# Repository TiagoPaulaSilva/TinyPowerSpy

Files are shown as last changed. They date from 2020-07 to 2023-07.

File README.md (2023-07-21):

# Tiny PowerSpy

 

Tiny PowerSpy is an IoT device, a smart plug for energy monitoring in wall outlets.

#### Compatible with: 
* [BitsTunnel](https://github.com/import-tiago/BitsTunnel)

## PCB Preview
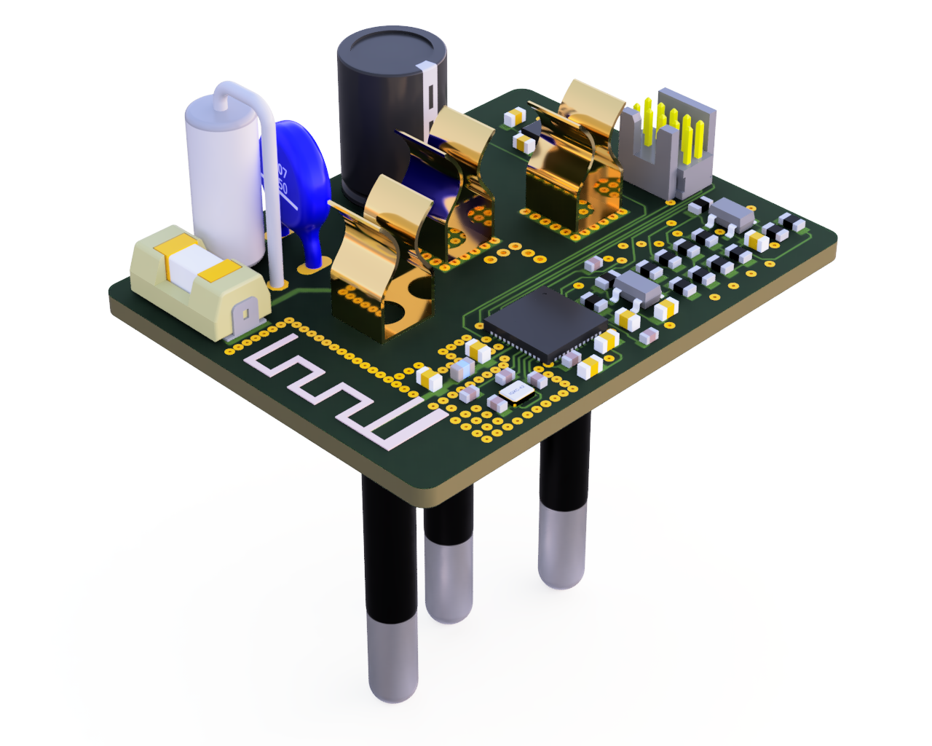
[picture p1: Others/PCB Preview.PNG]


## Enclosure Preview
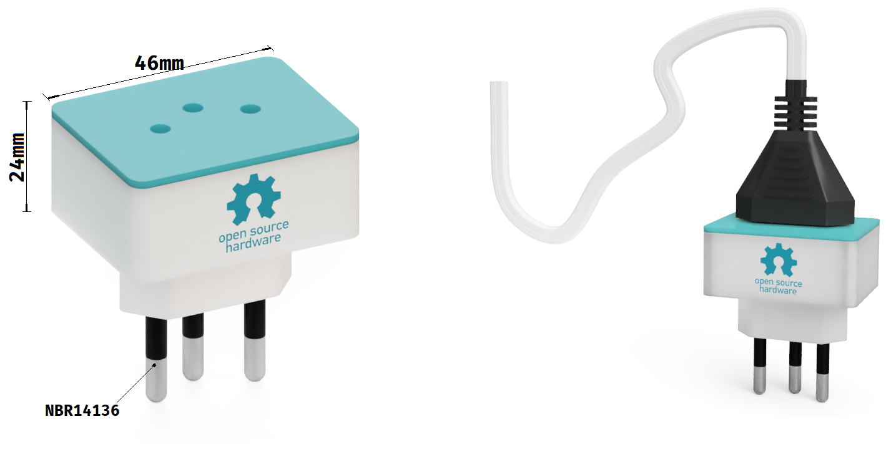
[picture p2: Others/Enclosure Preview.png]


## Schematic
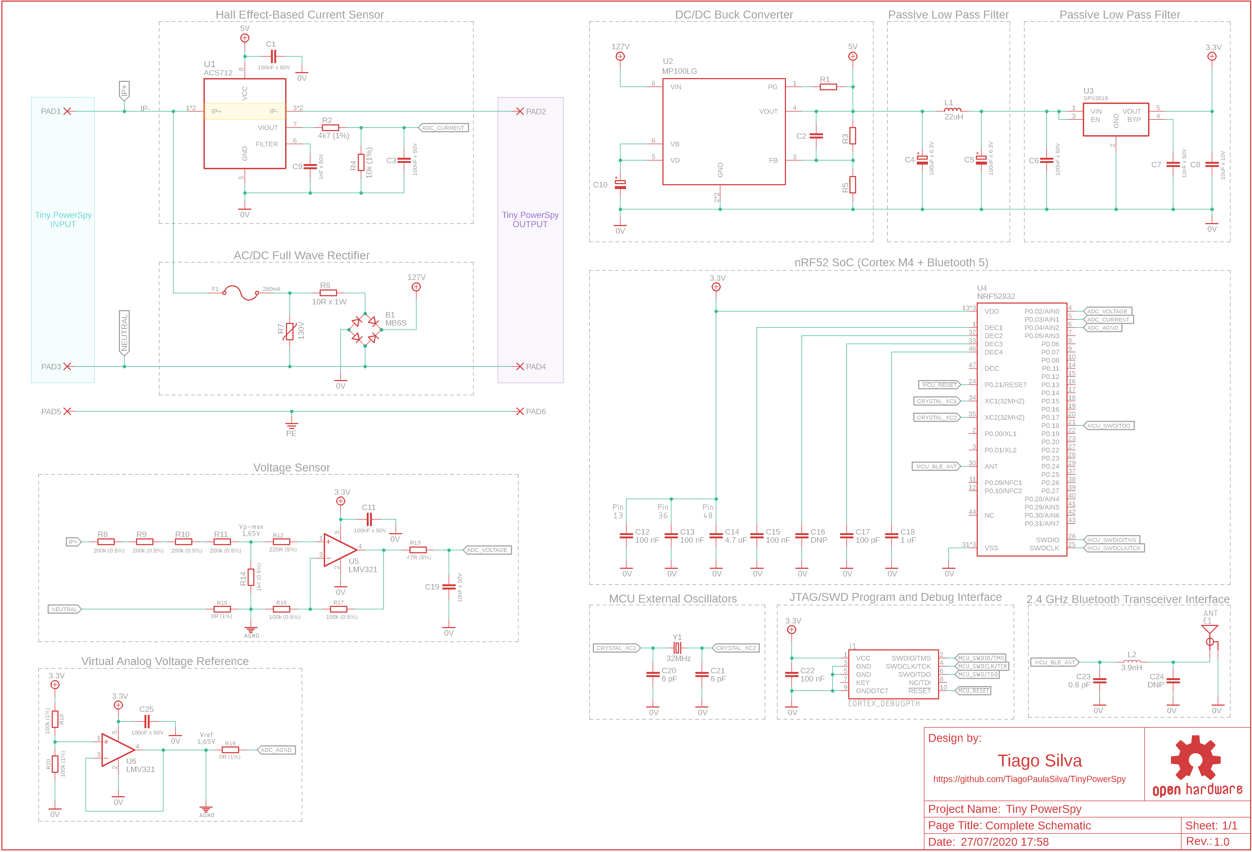
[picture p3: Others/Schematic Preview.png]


### Contributing
0. Give this project a :star:
1. Create an issue and describe your idea.
2. [Fork it](https://github.com/import-tiago/TinyPowerSpy/fork).
3. Create your feature branch (`git checkout -b my-new-feature`).
4. Commit your changes (`git commit -a -m "Added feature title"`).
5. Publish the branch (`git push origin my-new-feature`).
6. Create a new pull request.
7. Done! :heavy_check_mark:

### License Information
<br /><span xmlns:dct="http://purl.org/dc/terms/" property="dct:title">Light's Thrill</span> by <a xmlns:cc="http://creativecommons.org/ns#" href="https://github.com/import-tiago" property="cc:attributionName" rel="cc:attributionURL">Tiago Silva</a> is licensed under a <a rel="license" href="http://creativecommons.org/licenses/by-sa/4.0/">Creative Commons Attribution-ShareAlike 4.0 International License</a>.<br />
Permissions beyond the scope of this license may be available at <a xmlns:cc="http://creativecommons.org/ns#" href="https://twitter.com/import_tiago" rel="cc:morePermissions">tiagodepaulasilva@gmail.com</a>.

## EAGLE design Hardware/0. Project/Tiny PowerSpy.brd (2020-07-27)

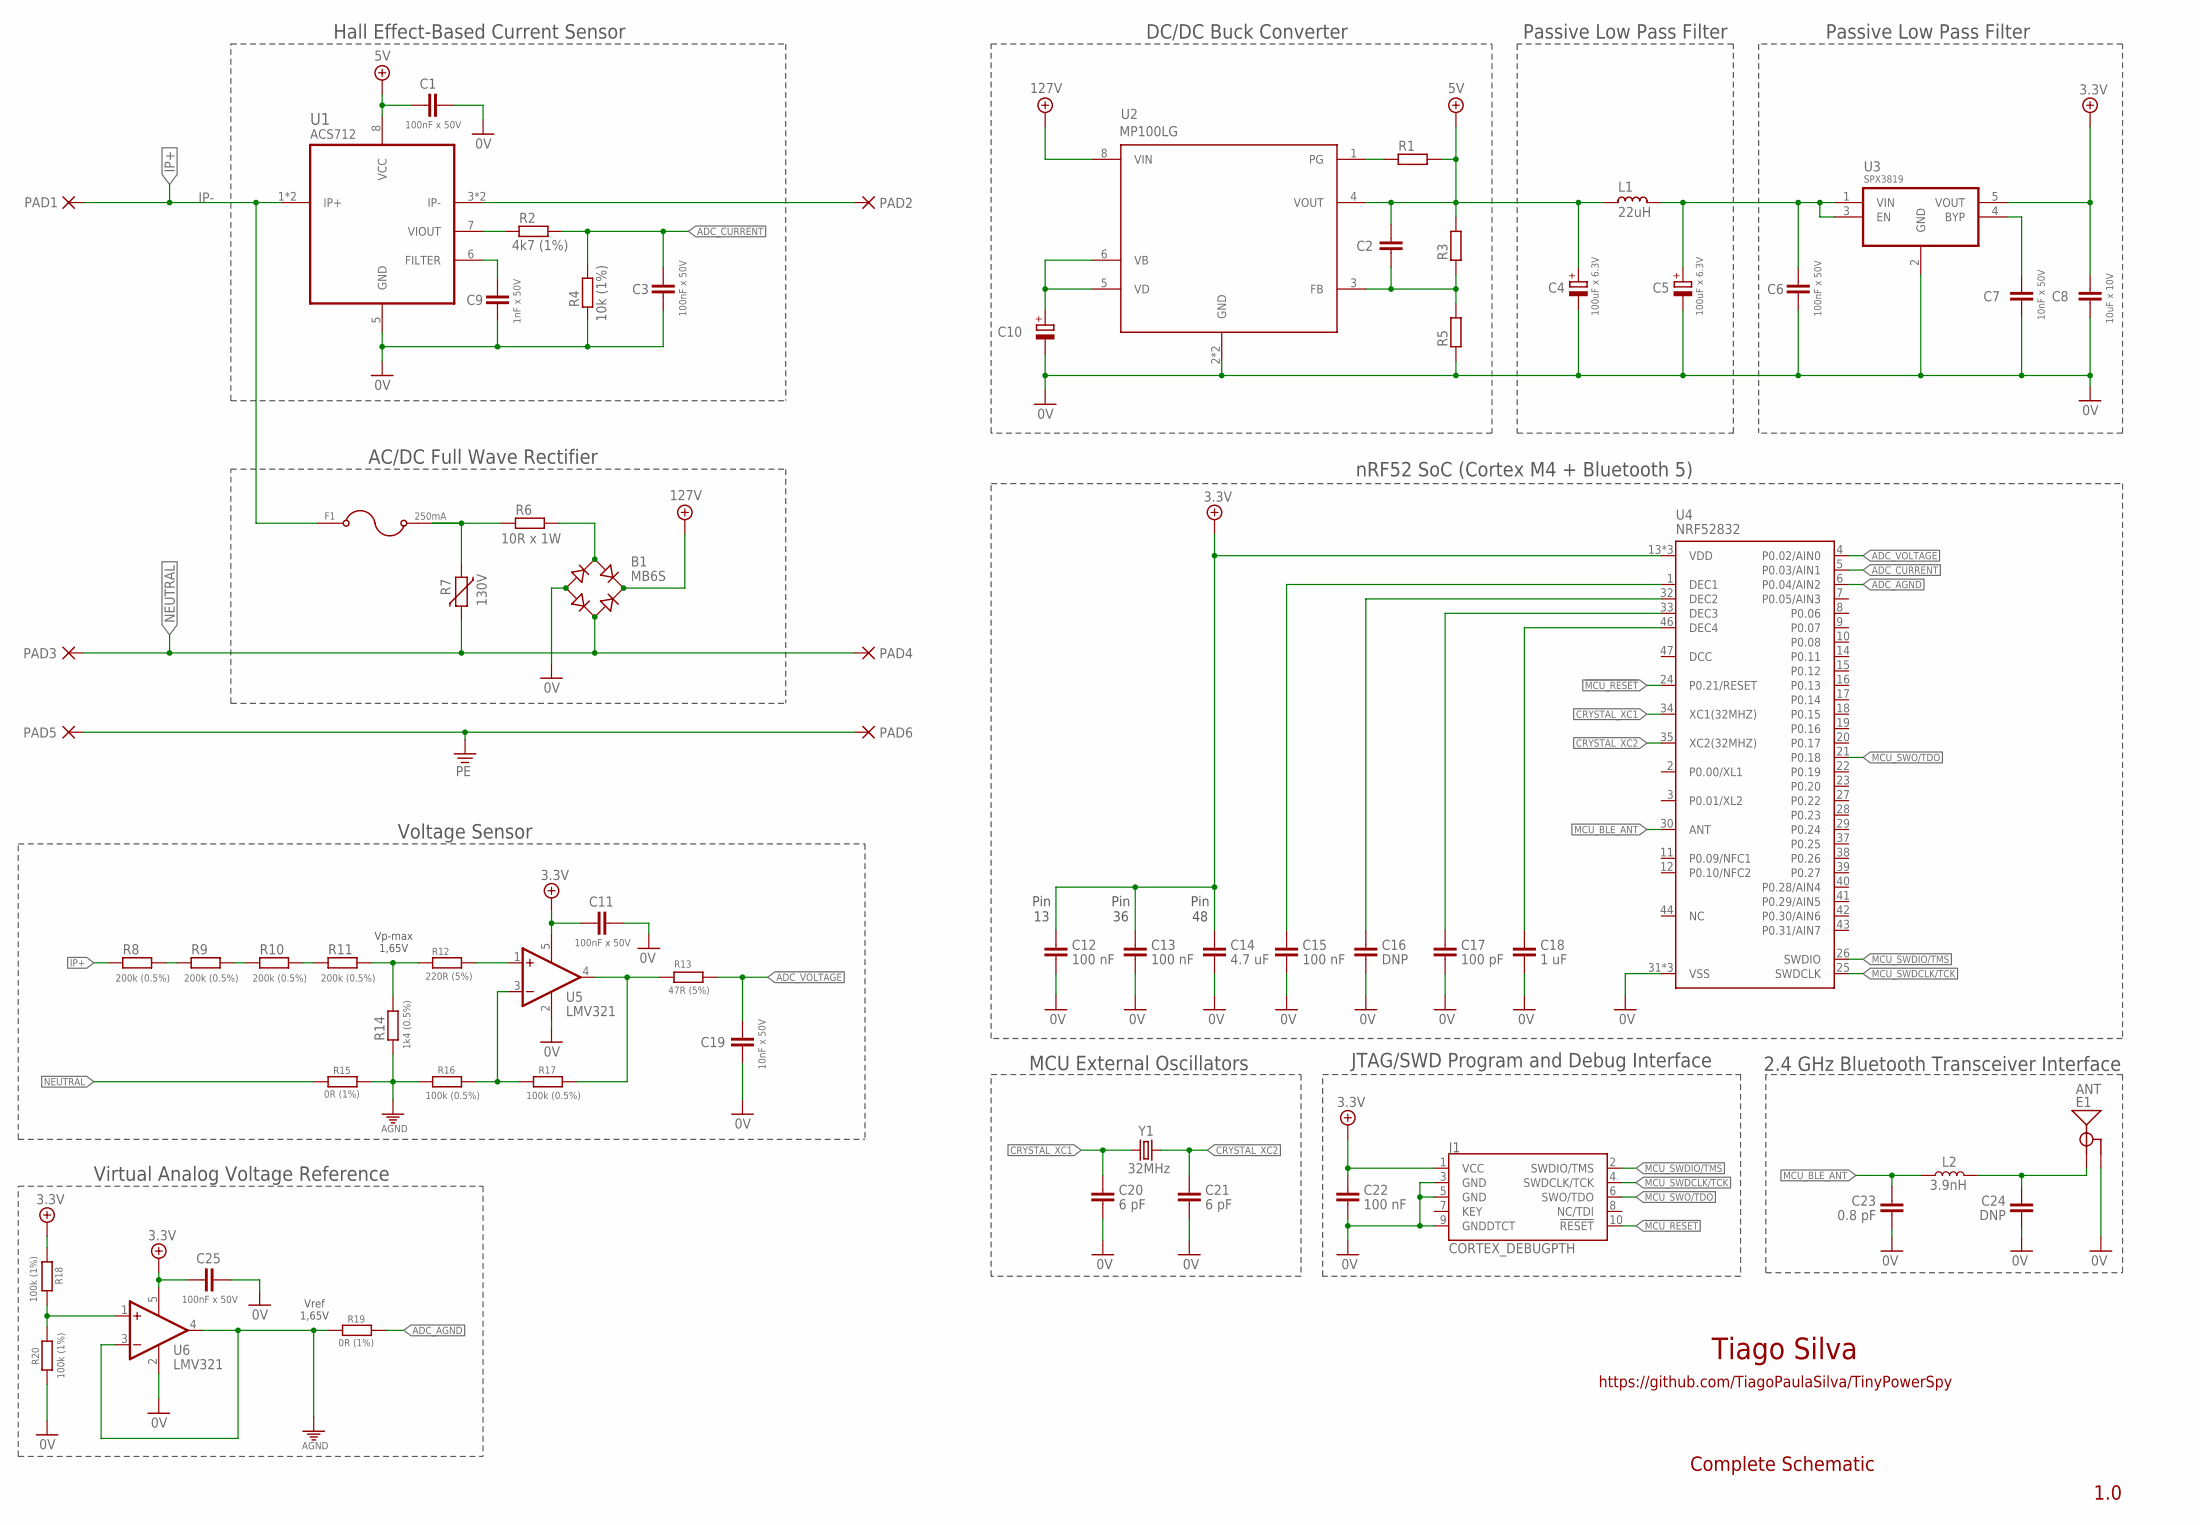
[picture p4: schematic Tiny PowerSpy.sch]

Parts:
B1: MB6S; SOIC-4
C1, C3, C6, C11, C25: 100nF x 50V; C0603
C2: C-EUC0603; C0603
C4, C5: 100uF x 6.3V; C1206K
C7, C19: 10nF x 50V; C0603
C8: 10uF x 10V; C0603
C9: 1nF x 50V; C0603
C10: CPOL-EUE3.5-8; E3,5-8
C12, C13, C15: 100 nF; C0402
C14: 4.7 uF; C0603
C16: DNP; C0402
C17: 100 pF; C0402
C18: 1 uF; C0603
C20, C21: 6 pF; C0402
C22: 100 nF; C0603
C23: 0.8 pF; C0603
C24: DNP; C0603
E1: ANT; TRACE_ANTENNA_2.4GHZ_15.2MM
F1: 250mA; FUSE_0154004.DR
J1: CORTEX_DEBUGPTH; 2X5-PTH-1.27MM
L1: 22uH; L0603
L2: 3.9nH; 0402
PAD1, PAD2, PAD4, PAD6: SMD5; SMD2,54-5,08
PAD3, PAD5: SMD2; SMD1,27-2,54
R1, R3, R5: R-EU_R0603; R0603
R2: 4k7 (1%); R0603
R4: 10k (1%); R0603
R6: 10R x 1W; 0207/5V
R7: 130V; S05K11
R8, R9, R10, R11: 200k (0.5%); R0603
R12: 220R (5%); R0603
R13: 47R (5%); R0603
R14: 1k4 (0.5%); R0603
R15, R19: 0R (1%); R0603
R16, R17: 100k (0.5%); R0603
R18, R20: 100k (1%); R0603
U1: ACS712; SOIC127P600X175-8N
U2: MP100LG; SOIC8E
U3: SPX3819; SOT95P280X145-5N
U4: NRF52832; QFN48-6X6MM
U5, U6: LMV321; SOT23-5
Y1: 32MHz; CRYSTAL-SMD-2.0X1.6MM

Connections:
0V: B1.-, C1.1, C3.2, C4.2, C5.2, C6.2, C7.2, C8.2, C9.2, C10.-, C11.1, C12.2, C13.2, C14.2, C15.2, C16.2, C17.2, C18.2, C19.2, C20.2, C21.2, C22.2, C23.2, C24.2, C25.2, E1.GND, J1.3 (GND), J1.5 (GND), J1.9 (GNDDTCT), R4.2, R5.1, R20.2, U1.5 (GND), U2.2 (GND), U2.9 (GND), U3.2 (GND), U4.31 (VSS), U4.45 (VSS), U4.EP (VSS), U5.2 (V-), U6.2 (V-)
3.3V: C8.1, C11.2, C12.1, C13.1, C14.1, C22.1, C25.1, J1.1 (VCC), R18.2, U3.5 (VOUT), U4.13 (VDD), U4.36 (VDD), U4.48 (VDD), U5.5 (V+), U6.5 (V+)
5V: C1.2, C2.1, C4.1, L1.2, R1.2, R3.2, U1.8 (VCC), U2.4 (VOUT)
127V: B1.+, U2.8 (VIN)
!MCU_RESET!: J1.10 (!RESET), U4.24 (P0.21/RESET)
ADC_AGND: R19.2, U4.6 (P0.04/AIN2)
ADC_CURRENT: C3.1, R2.2, R4.1, U4.5 (P0.03/AIN1)
ADC_VOLTAGE: C19.1, R13.1, U4.4 (P0.02/AIN0)
AGND: R14.2, R15.2, R16.2, R19.1, U6.3 (-IN), U6.4 (OUT)
CRYSTAL_XC1: C20.1, U4.34 (XC1(32MHZ)), Y1.3 (2)
CRYSTAL_XC2: C21.1, U4.35 (XC2(32MHZ)), Y1.1
IP+: F1.1, PAD1.1, R8.1, U1.1 (IP+), U1.2 (IP+)
IP-: PAD2.1, U1.3 (IP-), U1.4 (IP-)
MCU_BLE_ANT: C23.1, L2.2, U4.30 (ANT)
MCU_SWDCLK/TCK: J1.4 (SWDCLK/TCK), U4.25 (SWDCLK)
MCU_SWDIO/TMS: J1.2 (SWDIO/TMS), U4.26 (SWDIO)
MCU_SWO/TDO: J1.6 (SWO/TDO), U4.21 (P0.18)
unnamed: R1.1, U2.1 (PG)
unnamed: F1.2, R6.1, R7.1
unnamed: C16.1, U4.32 (DEC2)
unnamed: C2.2, R3.1, R5.2, U2.3 (FB)
unnamed: C10.+, U2.5 (VD), U2.6 (VB)
unnamed: C9.1, U1.6 (FILTER)
unnamed: B1.~1 (AC1), R6.2
unnamed: C15.1, U4.1 (DEC1)
unnamed: C18.1, U4.46 (DEC4)
unnamed: R2.1, U1.7 (VIOUT)
unnamed: C24.1, E1.ANT (SIGNAL), L2.1
unnamed: R9.2, R10.1
unnamed: C17.1, U4.33 (DEC3)
unnamed: R10.2, R11.1
unnamed: R13.2, R17.1, U5.4 (OUT)
unnamed: C5.1, C6.1, L1.1, U3.1 (VIN), U3.3 (EN)
unnamed: R8.2, R9.1
unnamed: C7.1, U3.4 (BYP)
unnamed: R16.1, R17.2, U5.3 (-IN)
unnamed: R11.2, R12.2, R14.1
unnamed: R12.1, U5.1 (+IN)
unnamed: R18.1, R20.1, U6.1 (+IN)
NEUTRAL: B1.~2 (AC2), PAD3.1, PAD4.1, R7.2, R15.1
PE: PAD5.1, PAD6.1

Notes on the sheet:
Tiago Silva
https://github.com/TiagoPaulaSilva/TinyPowerSpy
1.0
Complete Schematic
Vp-max 1,65V
Vref 1,65V
Pin 13
Pin 36
Pin 48
JTAG/SWD Program and Debug Interface
nRF52 SoC (Cortex M4 + Bluetooth 5)
MCU External Oscillators
2.4 GHz Bluetooth Transceiver Interface
DC/DC Buck Converter
Passive Low Pass Filter
AC/DC Full Wave Rectifier
Hall Effect-Based Current Sensor
Virtual Analog Voltage Reference
Voltage Sensor

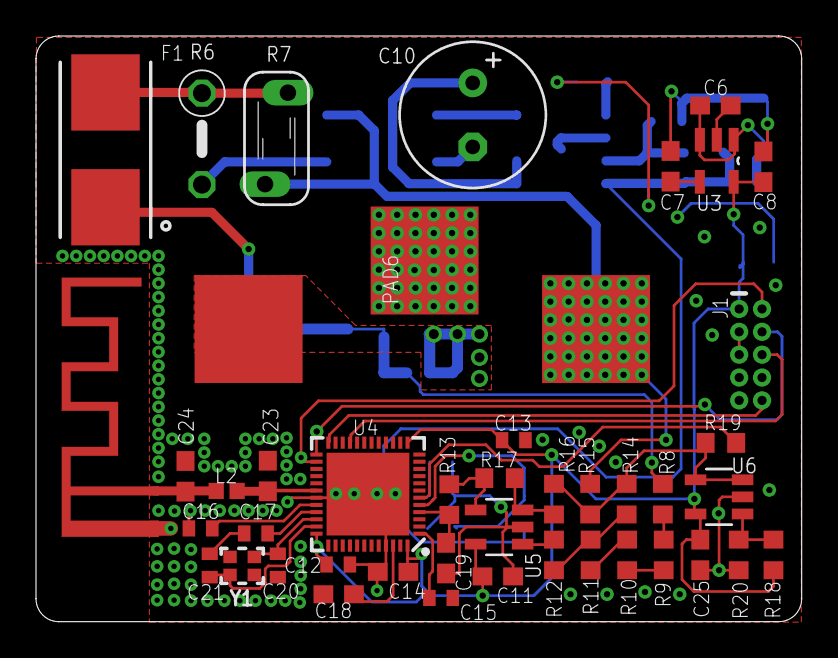
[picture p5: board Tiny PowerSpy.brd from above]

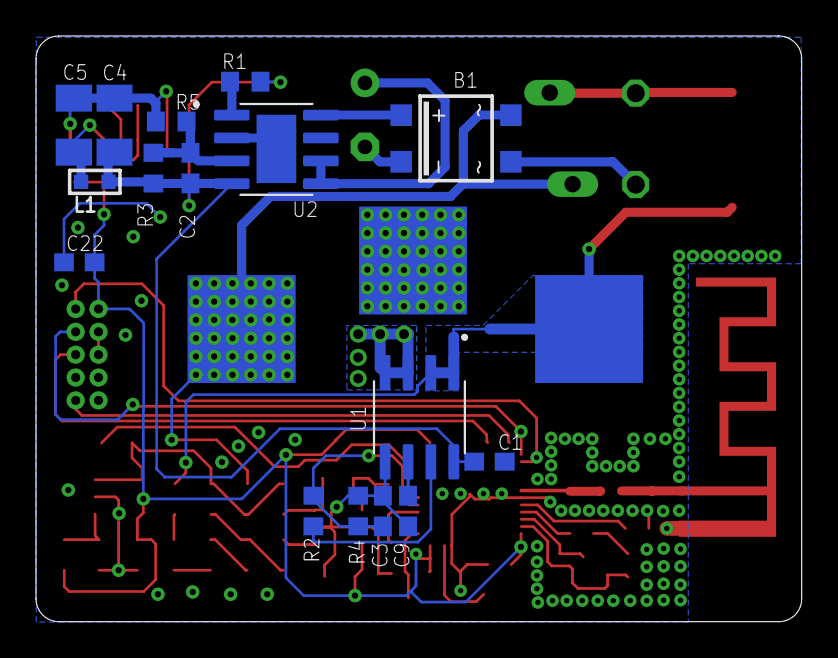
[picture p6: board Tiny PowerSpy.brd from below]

Board: 2 copper layers, 42.5 x 32.5 mm, 64 parts (19 on the bottom side), 41 nets.

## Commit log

2020-07-23 WIP - Schematic 1.0
    [Tiny PowerSpy.brd, Tiny PowerSpy.sch]
2020-07-23 Enclosure preview added
2020-07-26 PCB 1.0 - WIP
    [Tiny PowerSpy.brd, Tiny PowerSpy.sch]
2020-07-26 DC-DC buck IC added
2020-07-27 PCB 1.0 - Done
    [Tiny PowerSpy.brd, Tiny PowerSpy.sch]
2020-07-27 Gerber files from 1.0 project added
2020-07-27 Schematic preview added
2020-07-27 Minor improvements
    [Tiny PowerSpy.brd, Tiny PowerSpy.sch]
2020-07-27 PCB Preview added

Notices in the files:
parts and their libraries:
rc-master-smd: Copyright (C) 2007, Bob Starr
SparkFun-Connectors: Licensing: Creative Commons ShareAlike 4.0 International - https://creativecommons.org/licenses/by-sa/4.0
